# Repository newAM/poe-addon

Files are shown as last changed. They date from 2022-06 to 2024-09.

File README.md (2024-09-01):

# PoE Addon

Simple board to add power over Ethernet to a project.

This uses the [Wiznet W5500] for TCP/IP offload, and a [Microchip 25AA02E48] for
a valid EUI-48 MAC address.

## Bill of Materials

A bill of materials generated by [InteractiveHtmlBom] can be viewed at <https://newam.github.io/poe-addon/>

## Media

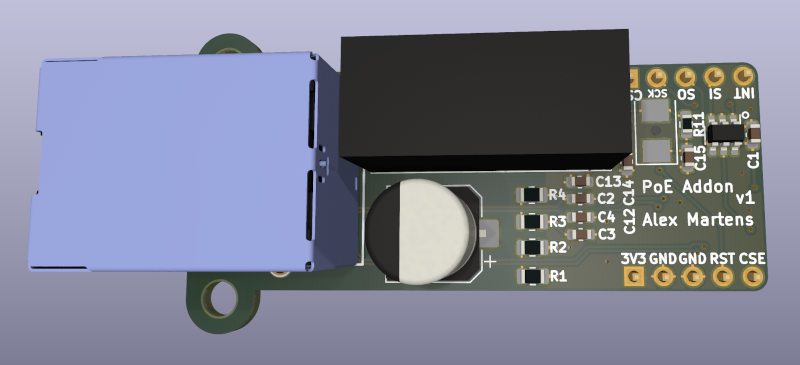
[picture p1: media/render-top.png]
3D Render Top

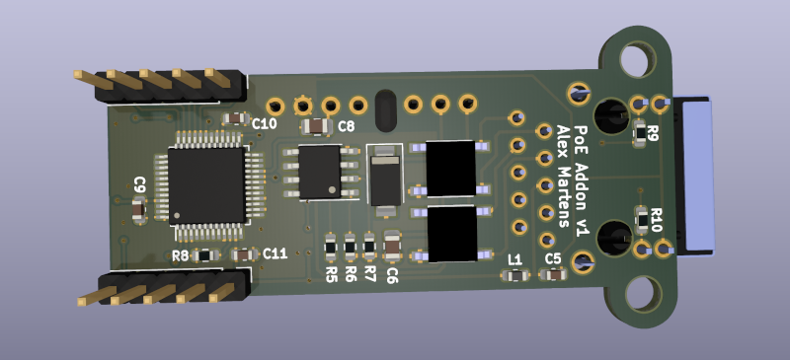
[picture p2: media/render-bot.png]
3D Render Bottom

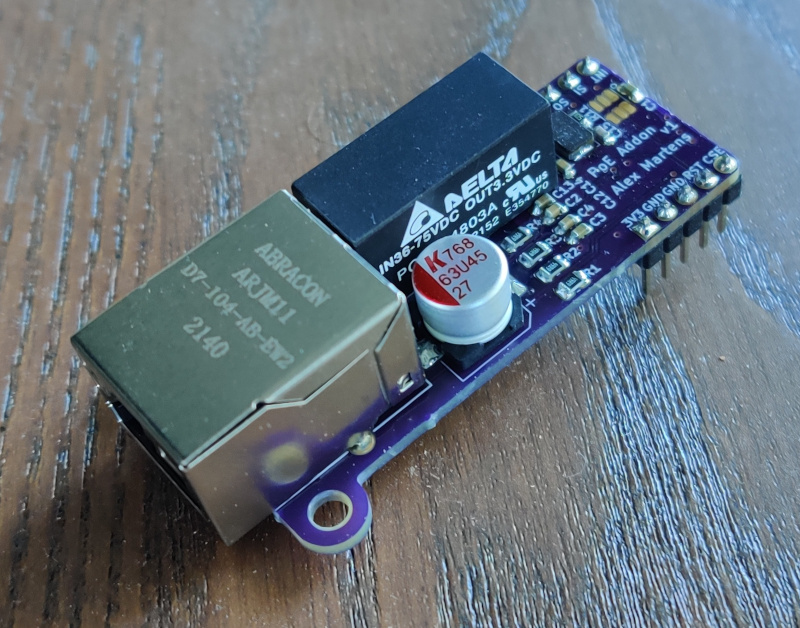
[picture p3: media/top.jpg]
Real Top

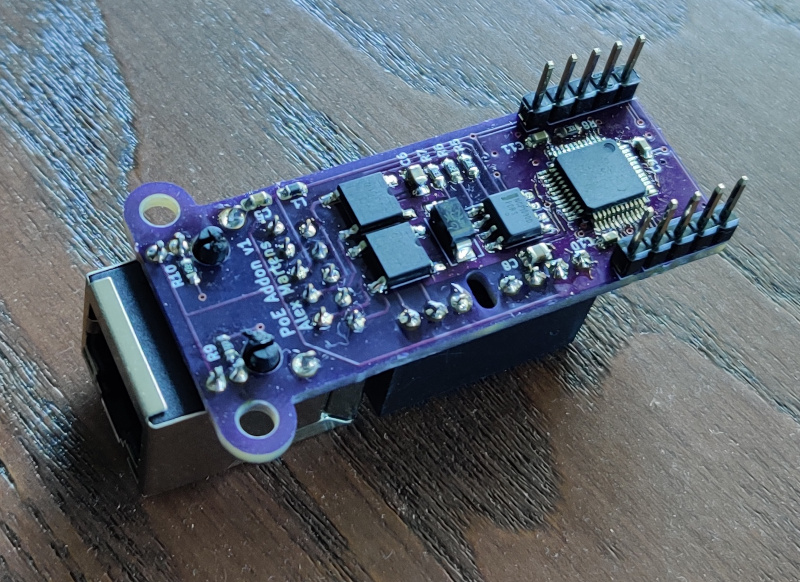
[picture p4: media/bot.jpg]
Real Bottom


## Software Used

- [KiCad](http://kicad.org/) 7.0.0 release

[InteractiveHtmlBom]: https://github.com/openscopeproject/InteractiveHtmlBom/issues
[Wiznet W5500]: https://www.wiznet.io/product-item/w5500/
[Microchip 25AA02E48]: http://ww1.microchip.com/downloads/en/devicedoc/22123a.pdf

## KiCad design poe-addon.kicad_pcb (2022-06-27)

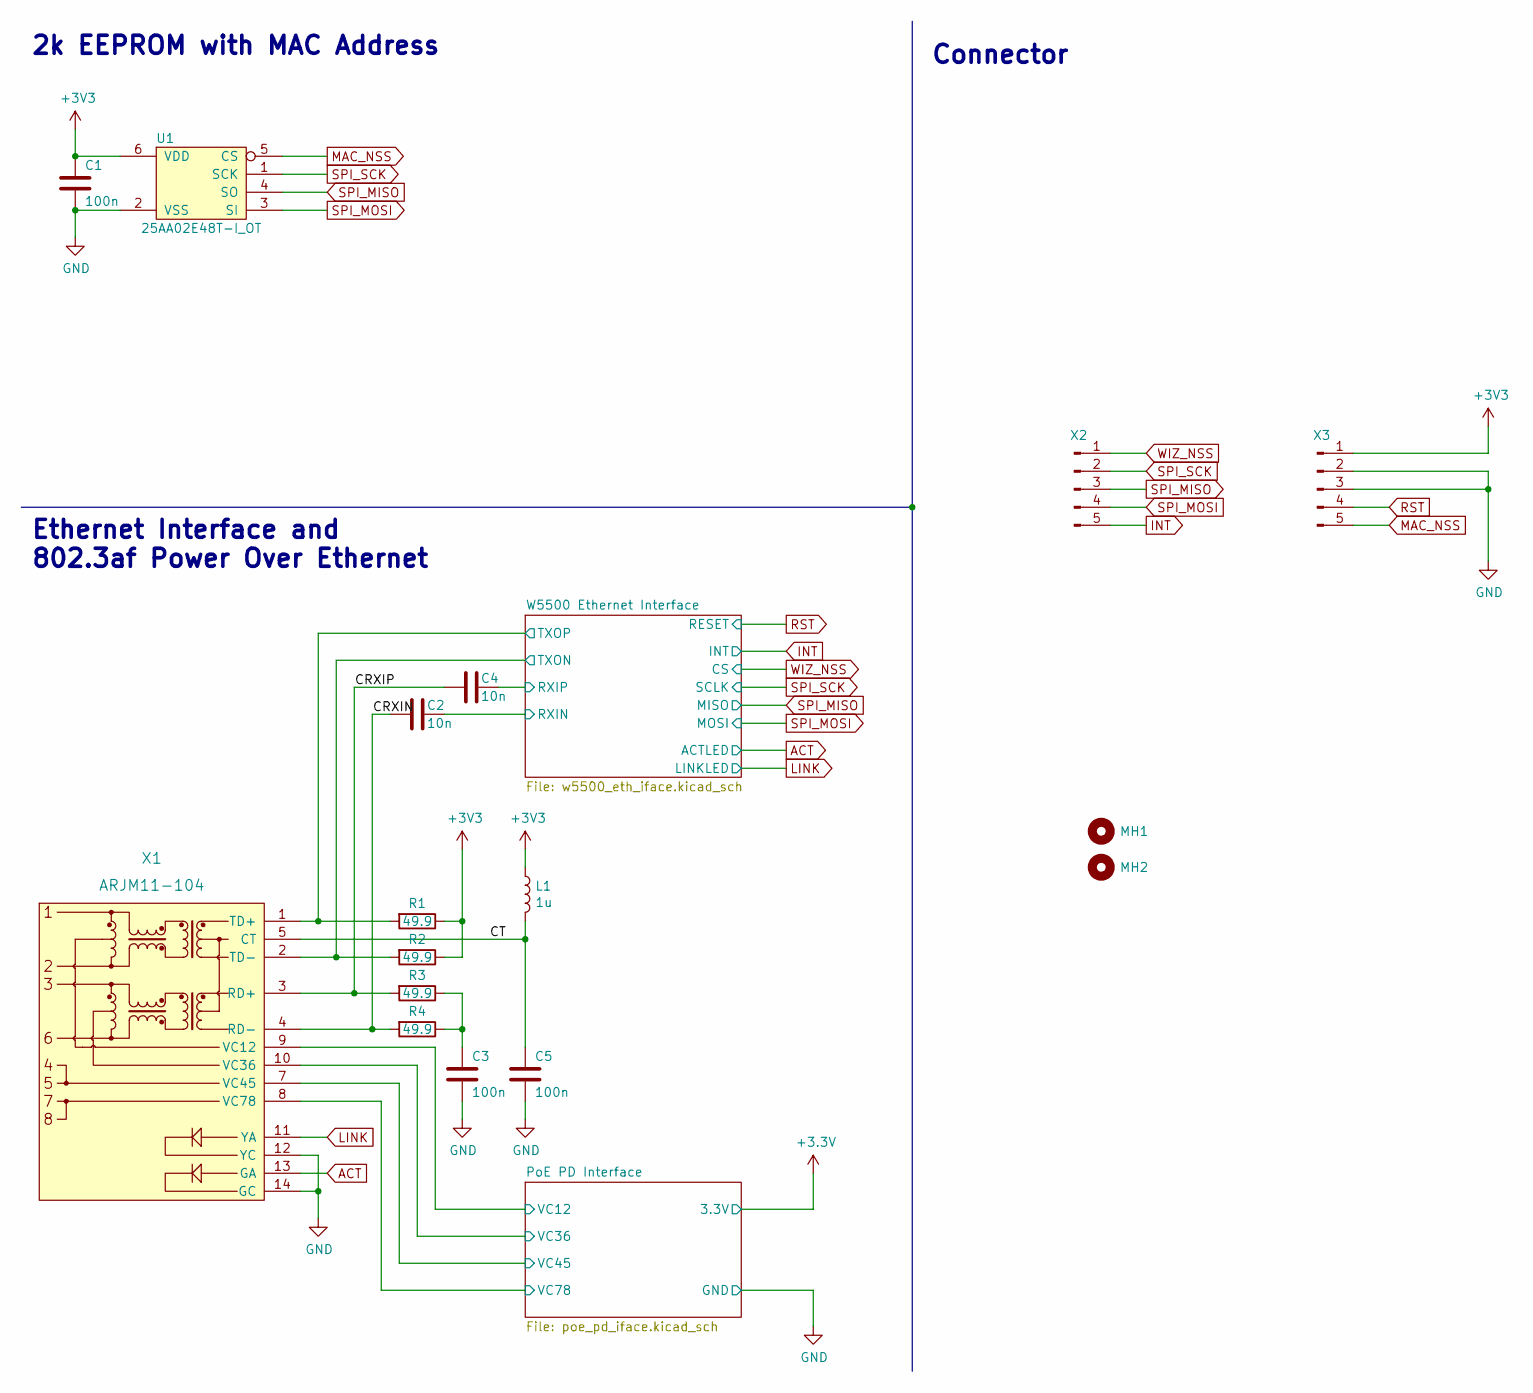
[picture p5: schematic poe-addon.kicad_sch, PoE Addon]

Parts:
C1, C3, C5: 100n; C_0603_1608Metric; Tolerance 10%; Voltage 16; DigiKey Part Number 1276-1005-1-ND
C2, C4: 10n; C_0603_1608Metric; Tolerance 10%; Voltage 50V; DigiKey Part Number 1276-1009-1-ND
L1: 1u; L_0603_1608Metric; Tolerance 20%; DigiKey Part Number 445-3163-1-ND
MH1, MH2: MountingHole; MountingHole_3.2mm_M3
R1, R2, R3, R4: 49.9; R_0805_2012Metric; Tolerance 1%; DigiKey Part Number RNCP0805FTD49R9CT-ND
U1: 25AA02E48T-I_OT; SOT-23-6; DigiKey Part Number 25AA02E48T-I/OT
X1: ARJM11-104; ARJM11D7-104-AB-EW2; DigiKey Part Number 535-14150-ND
X2, X3: Conn_01x05_Male; PinHeader_1x05_P2.54mm_Vertical

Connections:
/CRXIN: C2.2, R4.2, X1.4 (RD-)
/CRXIP: C4.2, R3.2, X1.3 (RD+)
/CT: C5.1, L1.2, X1.5 (CT)
/PoE PD Interface/VC12: X1.9 (VC12); also elsewhere on the board
/PoE PD Interface/VC36: X1.10 (VC36); also elsewhere on the board
/PoE PD Interface/VC45: X1.7 (VC45); also elsewhere on the board
/PoE PD Interface/VC78: X1.8 (VC78); also elsewhere on the board
/W5500 Ethernet Interface/RXIN: C2.1; also elsewhere on the board
/W5500 Ethernet Interface/RXIP: C4.1; also elsewhere on the board
/W5500 Ethernet Interface/TXON: R2.2, X1.2 (TD-); also elsewhere on the board
/W5500 Ethernet Interface/TXOP: R1.2, X1.1 (TD+); also elsewhere on the board
ACT: X1.13 (GA); also elsewhere on the board
GND: C1.2, C3.2, C5.2, U1.2 (VSS), X1.12 (YC), X1.14 (GC), X3.2, X3.3; also elsewhere on the board
INT: X2.5; also elsewhere on the board
LINK: X1.11 (YA); also elsewhere on the board
MAC_NSS: U1.5 (CS), X3.5
unnamed: C3.1, R3.1, R4.1
RST: X3.4; also elsewhere on the board
SPI_MISO: U1.4 (SO), X2.3; also elsewhere on the board
SPI_MOSI: U1.3 (SI), X2.4; also elsewhere on the board
SPI_SCK: U1.1 (SCK), X2.2; also elsewhere on the board
WIZ_NSS: X2.1; also elsewhere on the board

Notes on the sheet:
2k EEPROM with MAC Address
Connector
Ethernet Interface and 802.3af Power Over Ethernet

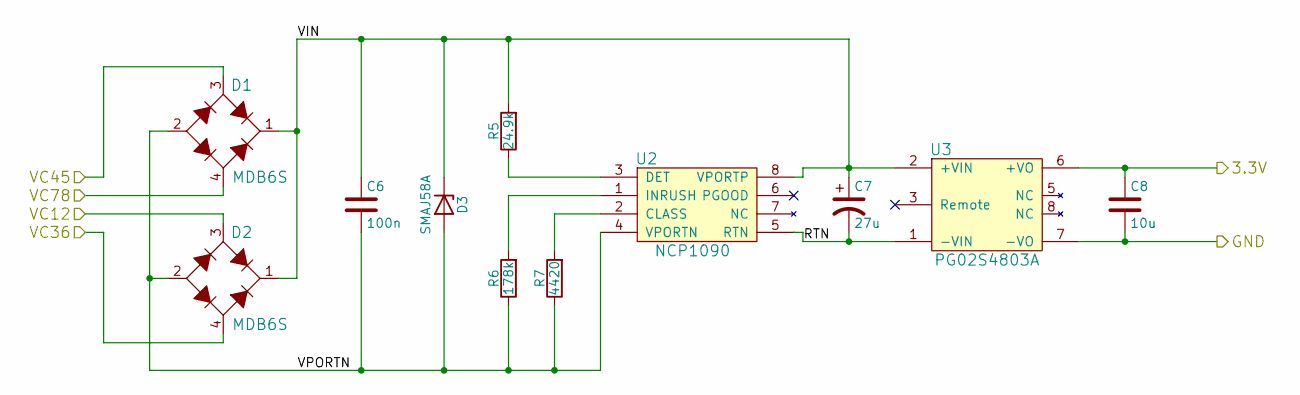
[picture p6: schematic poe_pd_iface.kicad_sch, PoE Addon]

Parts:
C6: 100n; C_0805_2012Metric; DigiKey Part Number 1276-6840-1-ND
C7: 27u; CP_Elec_8x10.5; DigiKey Part Number 399-A768KE276M1JLAE054CT-ND
C8: 10u; C_0805_2012Metric; DigiKey Part Number 1276-6456-1-ND
D1, D2: MDB6S; Micro-DIP-4; DigiKey Part Number MDB6SFSCT-ND
D3: SMAJ58A; D_SMA; DigiKey Part Number SMAJ58A-E3/61GICT-ND
R5: 24.9k; R_0603_1608Metric; DigiKey Part Number 311-24.9KHRCT-ND
R6: 178k; R_0603_1608Metric; DigiKey Part Number 311-178KHRCT-ND
R7: 4420; R_0603_1608Metric; DigiKey Part Number 311-4.42KHRCT-ND
U2: NCP1090; SOIC-8_3.9x4.9mm_P1.27mm; DigiKey Part Number NCP1090DRGOSCT-ND
U3: PG02S4803A; PG02S; DigiKey Part Number 941-1185-ND

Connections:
/PoE PD Interface/RTN: C7.2, U2.5 (RTN), U3.1 (-VIN)
/PoE PD Interface/VC12: D2.3 (AC1); also elsewhere on the board
/PoE PD Interface/VC36: D2.4 (AC2); also elsewhere on the board
/PoE PD Interface/VC45: D1.3 (AC1); also elsewhere on the board
/PoE PD Interface/VC78: D1.4 (AC2); also elsewhere on the board
/PoE PD Interface/VIN: C6.1, C7.1, D1.1 (+), D2.1 (+), D3.1 (K), R5.2, U2.8 (VPORTP), U3.2 (+VIN)
/PoE PD Interface/VPORTN: C6.2, D1.2 (-), D2.2 (-), D3.2 (A), R6.1, R7.1, U2.4 (VPORTN)
GND: C8.2, U3.7 (-VO); also elsewhere on the board
unnamed: R5.1, U2.3 (DET)
unnamed: R6.2, U2.1 (INRUSH)
unnamed: R7.2, U2.2 (CLASS)

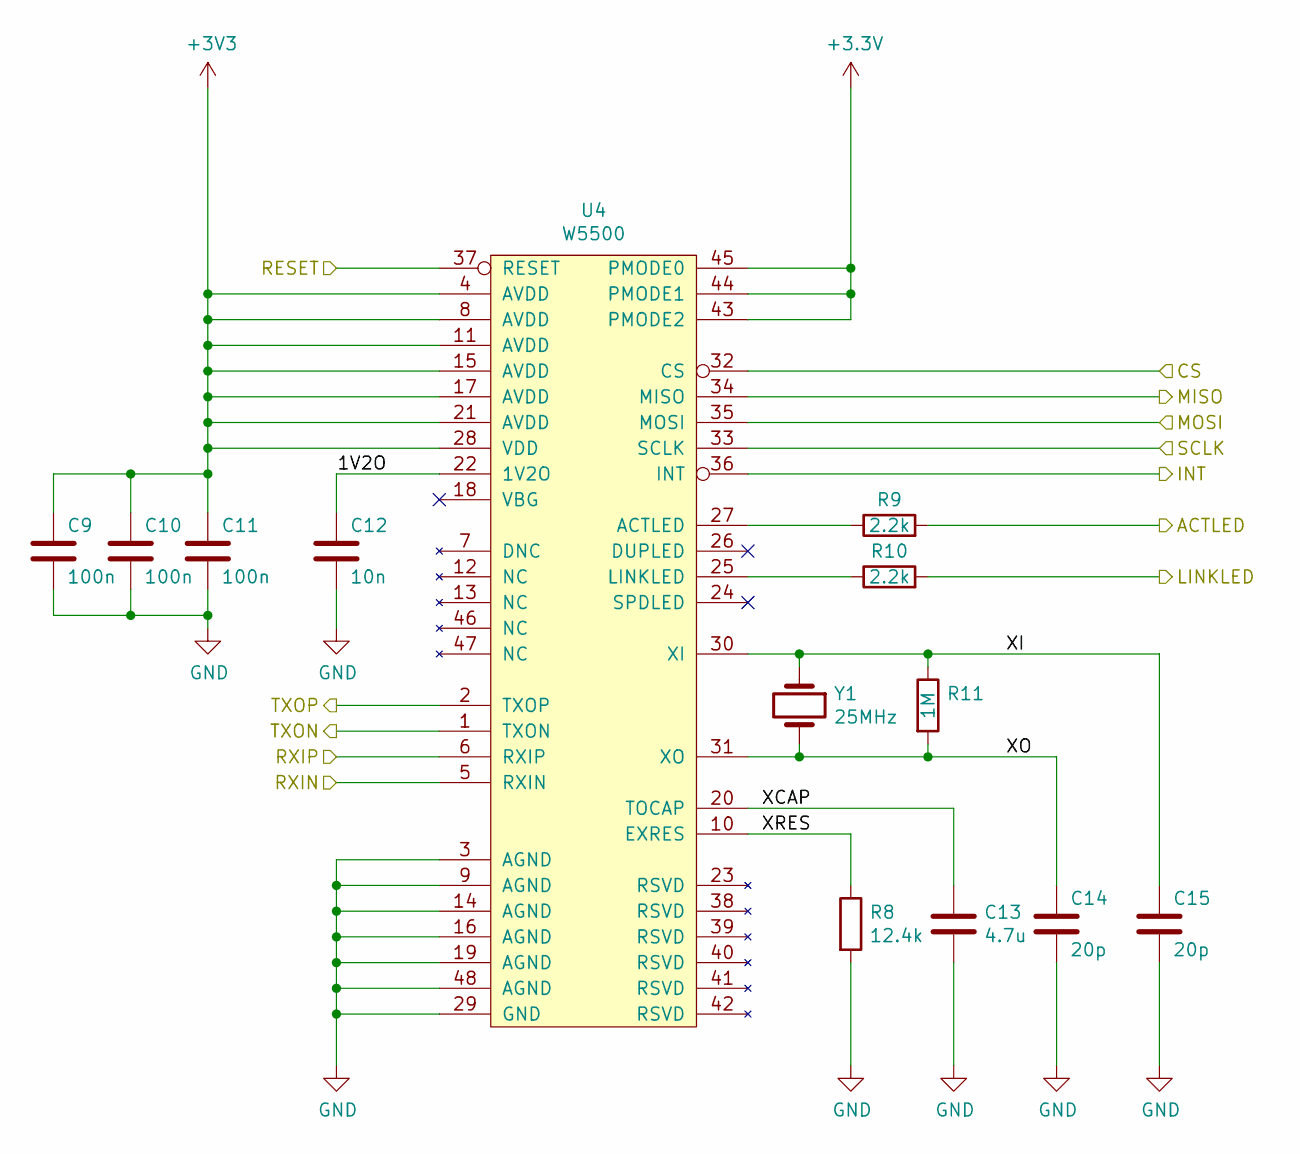
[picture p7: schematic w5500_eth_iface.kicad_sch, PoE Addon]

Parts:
C9, C10, C11: 100n; C_0603_1608Metric; DigiKey Part Number 1276-1012-1-ND
C12: 10n; C_0603_1608Metric; DigiKey Part Number 1276-1009-1-ND
C13: 4.7u; C_0603_1608Metric; DigiKey Part Number 1276-1907-1-ND
C14, C15: 20p; C_0603_1608Metric; DigiKey Part Number 1276-1187-1-ND
R8: 12.4k; R_0603_1608Metric; Tolerance ±1%; DigiKey Part Number 311-12.4KHRCT-ND
R9, R10: 2.2k; R_0603_1608Metric; DigiKey Part Number 311-2.20KHRCT-ND
R11: 1M; R_0603_1608Metric; DigiKey Part Number 311-1.0MGRCT-ND
U4: W5500; LQFP-48_7x7mm_P0.5mm; DigiKey Part Number 1278-1021-ND
Y1: 25MHz; Crystal_SMD_5032-2Pin_5.0x3.2mm; DigiKey Part Number CTX1175CT-ND

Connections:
/W5500 Ethernet Interface/1V2O: C12.1, U4.22 (1V2O)
/W5500 Ethernet Interface/RXIN: U4.5 (RXIN); also elsewhere on the board
/W5500 Ethernet Interface/RXIP: U4.6 (RXIP); also elsewhere on the board
/W5500 Ethernet Interface/TXON: U4.1 (TXON); also elsewhere on the board
/W5500 Ethernet Interface/TXOP: U4.2 (TXOP); also elsewhere on the board
/W5500 Ethernet Interface/XCAP: C13.1, U4.20 (TOCAP)
/W5500 Ethernet Interface/XI: C15.1, R11.1, U4.30 (XI), Y1.1
/W5500 Ethernet Interface/XO: C14.1, R11.2, U4.31 (XO), Y1.2
/W5500 Ethernet Interface/XRES: R8.1, U4.10 (EXRES)
ACT: R9.2; also elsewhere on the board
GND: C9.2, C10.2, C11.2, C12.2, C13.2, C14.2, C15.2, R8.2, U4.3 (AGND), U4.9 (AGND), U4.14 (AGND), U4.16 (AGND), U4.19 (AGND), U4.29 (GND), U4.48 (AGND); also elsewhere on the board
INT: U4.36 (INT); also elsewhere on the board
LINK: R10.2; also elsewhere on the board
unnamed: R9.1, U4.27 (ACTLED)
unnamed: R10.1, U4.25 (LINKLED)
RST: U4.37 (RESET); also elsewhere on the board
SPI_MISO: U4.34 (MISO); also elsewhere on the board
SPI_MOSI: U4.35 (MOSI); also elsewhere on the board
SPI_SCK: U4.33 (SCLK); also elsewhere on the board
WIZ_NSS: U4.32 (CS); also elsewhere on the board

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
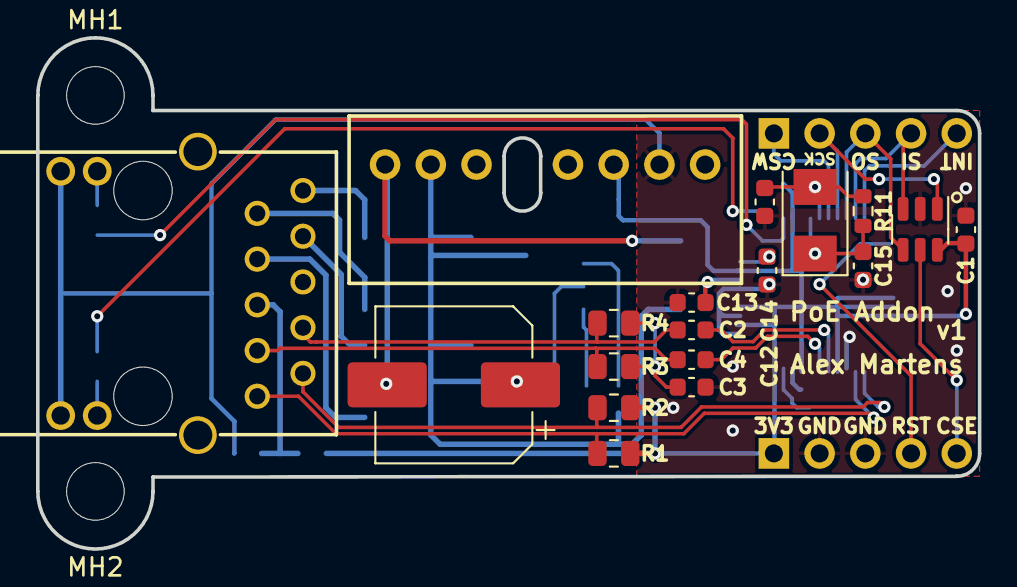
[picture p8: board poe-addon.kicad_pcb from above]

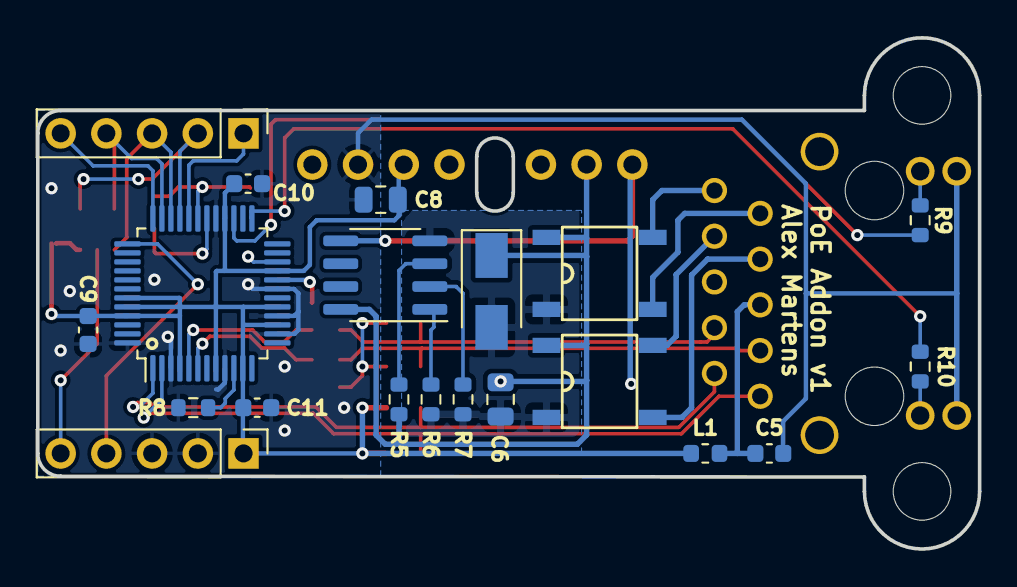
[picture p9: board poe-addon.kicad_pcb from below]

Board: 2 copper layers, 52.3 x 28.4 mm, 40 parts (20 on the bottom side), 36 nets.

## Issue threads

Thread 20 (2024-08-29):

Built and tested?

jamislike, 2024-08-29:
I notice in the current readme you say "Proceed with caution, I have not made this yet due to part shortages."

Did you ever build and test it to confirm the circuit works?
Thanks!

newAM, 2024-08-29:
I did build three with everything but the microchip EEPROM which was still out of stock.

I've been using one for over two years as hub for my DIY long range temperature sensors (not on GitHub, still need to clean this up 😅).

I'll update the readme and add some photos when I'm at my desktop later today!

Closed 2024-09-01.

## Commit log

2022-06-26 add pg02s 3D model
    [poe-addon.kicad_pcb, poe-addon.kicad_sch, poe_pd_iface.kicad_sch]
2022-06-26 Add interactive bill of materials
2022-06-26 README: add link to BOM
2022-06-26 bom: add digikey part numbers
2022-06-26 10nF 0603: 1276-1921-1-ND -> 1276-1009-1-ND
    [poe-addon.kicad_pcb, poe-addon.kicad_sch, w5500_eth_iface.kicad_sch]
2022-06-26 NCP1090: NCP1090DGOS-ND -> NCP1090DRGOSCT-ND
    [poe-addon.kicad_pcb, poe_pd_iface.kicad_sch]
2022-06-26 22uF electrolytic: replace with 27uF for stock reasons
    399-A768KE226M1JLAE054TR-ND -> 399-A768KE276M1JLAE054CT-ND
    [poe-addon.kicad_pcb, poe-addon.kicad_sch, poe_pd_iface.kicad_sch]
2022-06-26 w5500 crystal: CTX1437CT-ND -> CTX1175CT-ND
    [poe-addon.kicad_pcb, w5500_eth_iface.kicad_sch]
2022-06-27 add mounting holes, replace magjack with in-stock part
    [poe-addon.kicad_pcb, poe-addon.kicad_sch, poe_pd_iface.kicad_sch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]
2022-06-27 update date
    [poe-addon.kicad_pcb, poe-addon.kicad_sch, poe_pd_iface.kicad_sch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]
2023-07-15 flake.lock: update
    • Updated input 'nixpkgs':
    'github:nixos/nixpkgs/f2537a505d45c31fe5d9c27ea9829b6f4c4e6ac5' (2022-06-26)
    → 'github:nixos/nixpkgs/e74e68449c385db82de3170288a28cd0f608544f' (2023-07-13)
2023-07-24 Add LCSC part numbers
    [poe-addon.kicad_sch, poe_pd_iface.kicad_sch, w5500_eth_iface.kicad_sch]
2024-09-01 README: add media of real device
2024-09-01 flake.lock: update
    • Updated input 'interactive-html-bom':
    'github:newam/interactive-html-bom-nix/456e86bd2550811073850cde7699b7779c54eb7f' (2022-06-26)
    → 'github:newam/interactive-html-bom-nix/d7c659eca0a94c0a75543d699e1024d84583afdf' (2024-09-01)
    'github:nixos/nixpkgs/e74e68449c385db82de3170288a28cd0f608544f' (2023-07-13)
    → 'github:nixos/nixpkgs/12228ff1752d7b7624a54e9c1af4b222b3c1073b' (2024-08-31)
    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
